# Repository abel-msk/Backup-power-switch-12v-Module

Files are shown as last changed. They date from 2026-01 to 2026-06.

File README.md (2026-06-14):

#Power backup board

Board for 12v power switch.  Plain power and battery backup.  Switchng provided by LM393 comparator. Both compared   line are adjustable by potentiometer.
Equipped with:
Battery 3S charger, 
Two INA219 i2c sensors
ESP32-C3 wifi board
Charge and done charger led signals passed to ESP
1x External connector for i2c line and charger status 
1x Connector with SPI for ext display
4x 12v power connector

First version
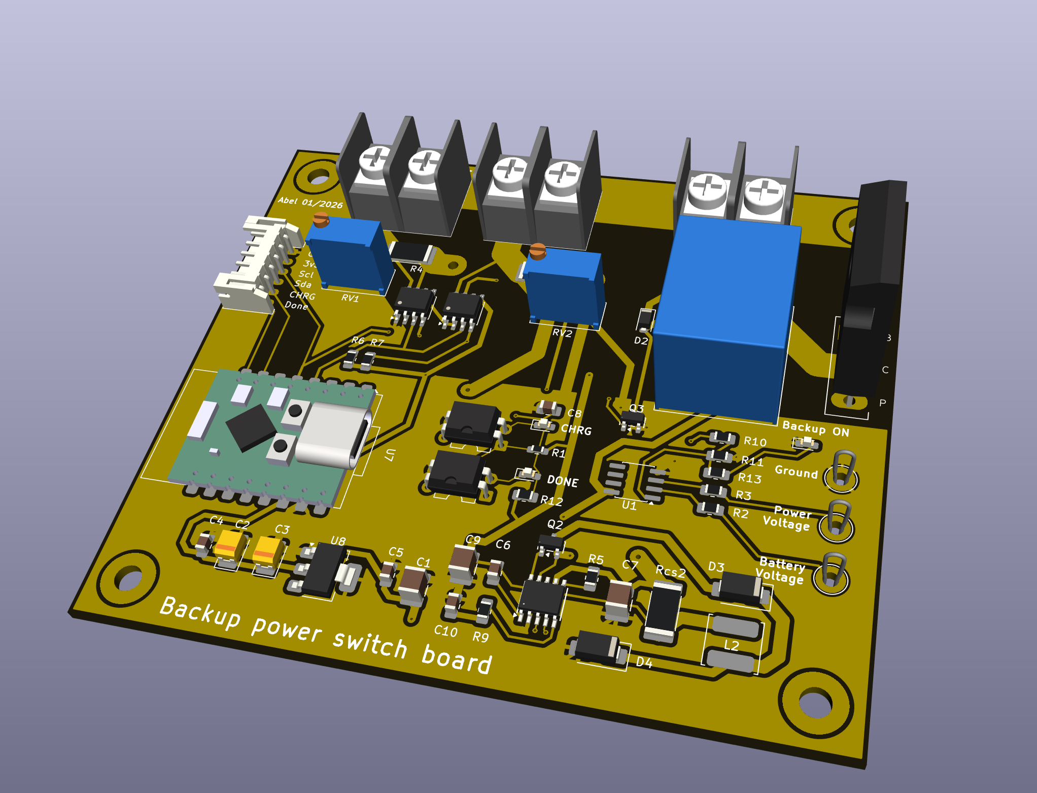
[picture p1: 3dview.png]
3D View


Current version v3.1
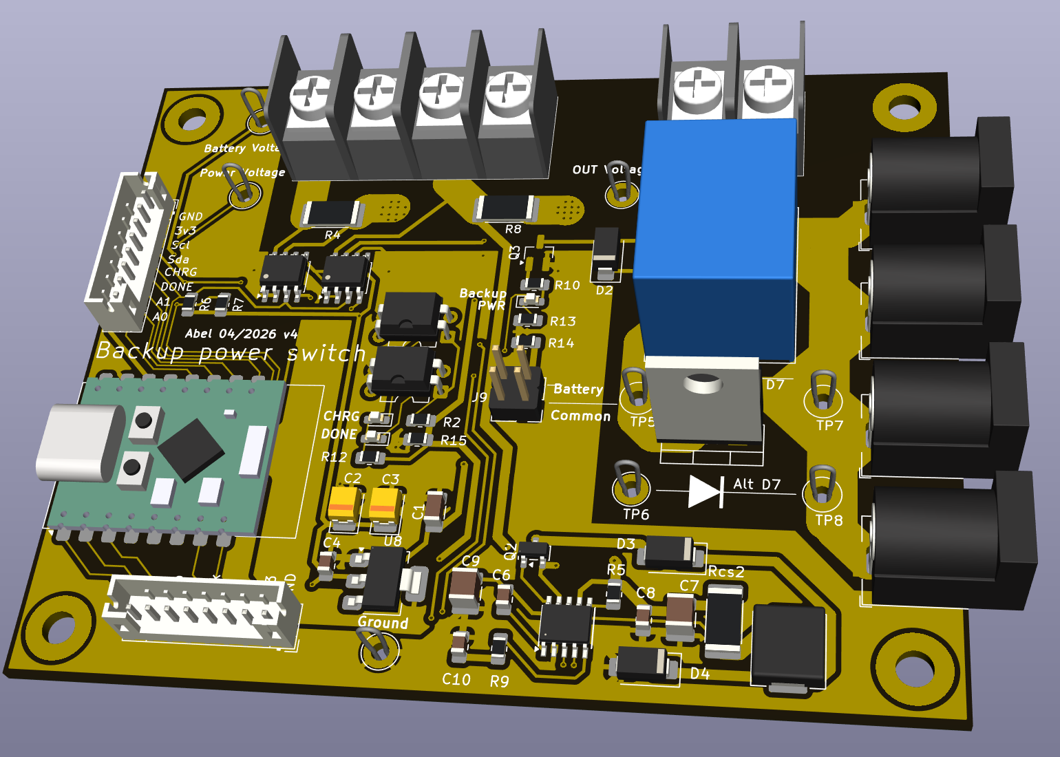
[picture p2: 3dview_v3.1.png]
3D View v3.1


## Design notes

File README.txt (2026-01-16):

# Power backup board

Board for 12v power switch.  Plain power and battery backup.  Switchng provided by LM393 comparator. Both compared   line are adjustable by potentiometer.
Equipped with:
Battery 3S charger, 
Two INA219 i2c sensors
ESP32-C3 wifi board
Charge and done charger passed to ESP
External connector for i2x line and charger status

3D View

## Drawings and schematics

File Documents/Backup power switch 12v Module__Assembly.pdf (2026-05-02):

AB

AB

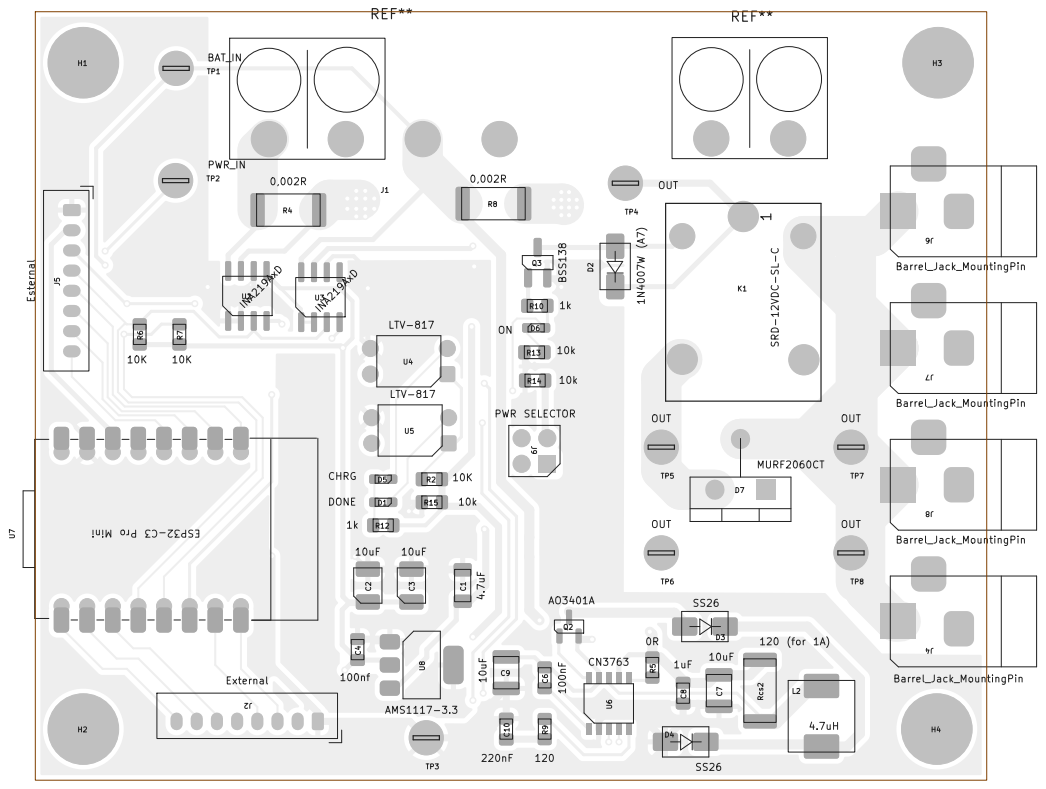
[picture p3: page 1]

Board2Pdf: Light Colors Placement TOP - Page 1/2

Sheet: Light Colors Placement TOP
File: Backup power switch 12v Module.kicad_pcb
Title:
KiCad E.D.A. 10.0.1

TP8 C8 C9 | D2 | Rcs2 U8 | U6 U7 | D7 U3 Antenna 1 | 2 | 3 | 4 | 5 | 6

AB

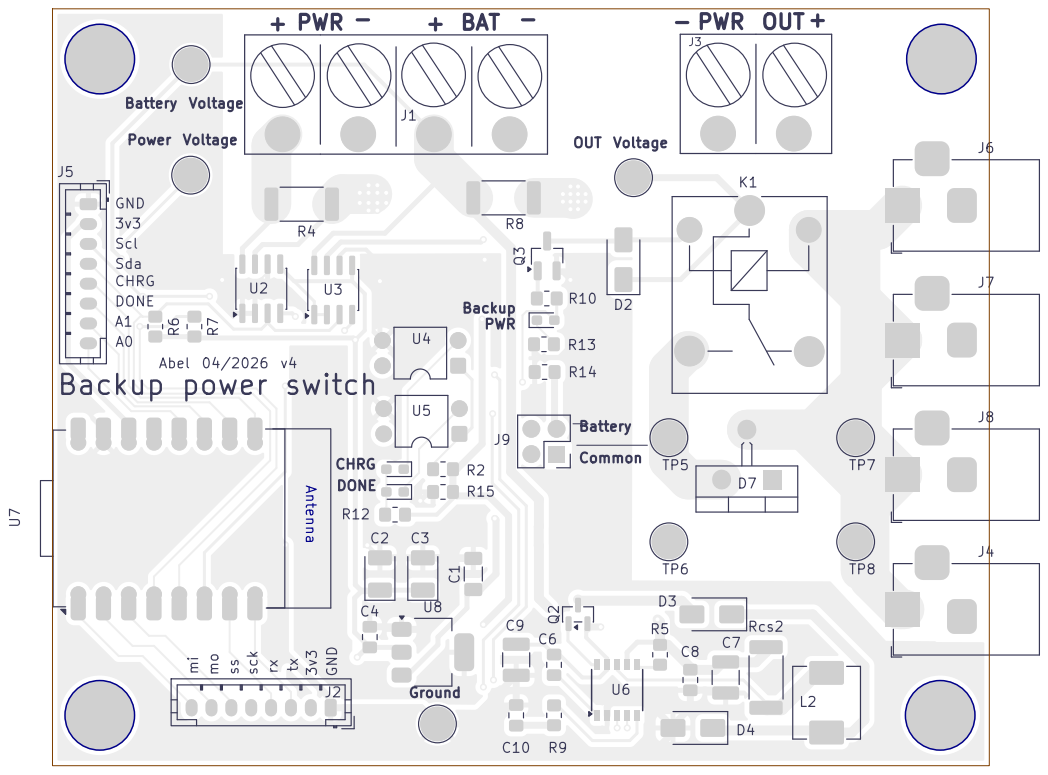
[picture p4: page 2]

Board2Pdf: Light Colors PCB Fabrication TOP - Page 2/2

Sheet: Light Colors PCB Fabrication TOP
File: Backup power switch 12v Module.kicad_pcb
Title:
KiCad E.D.A. 10.0.1

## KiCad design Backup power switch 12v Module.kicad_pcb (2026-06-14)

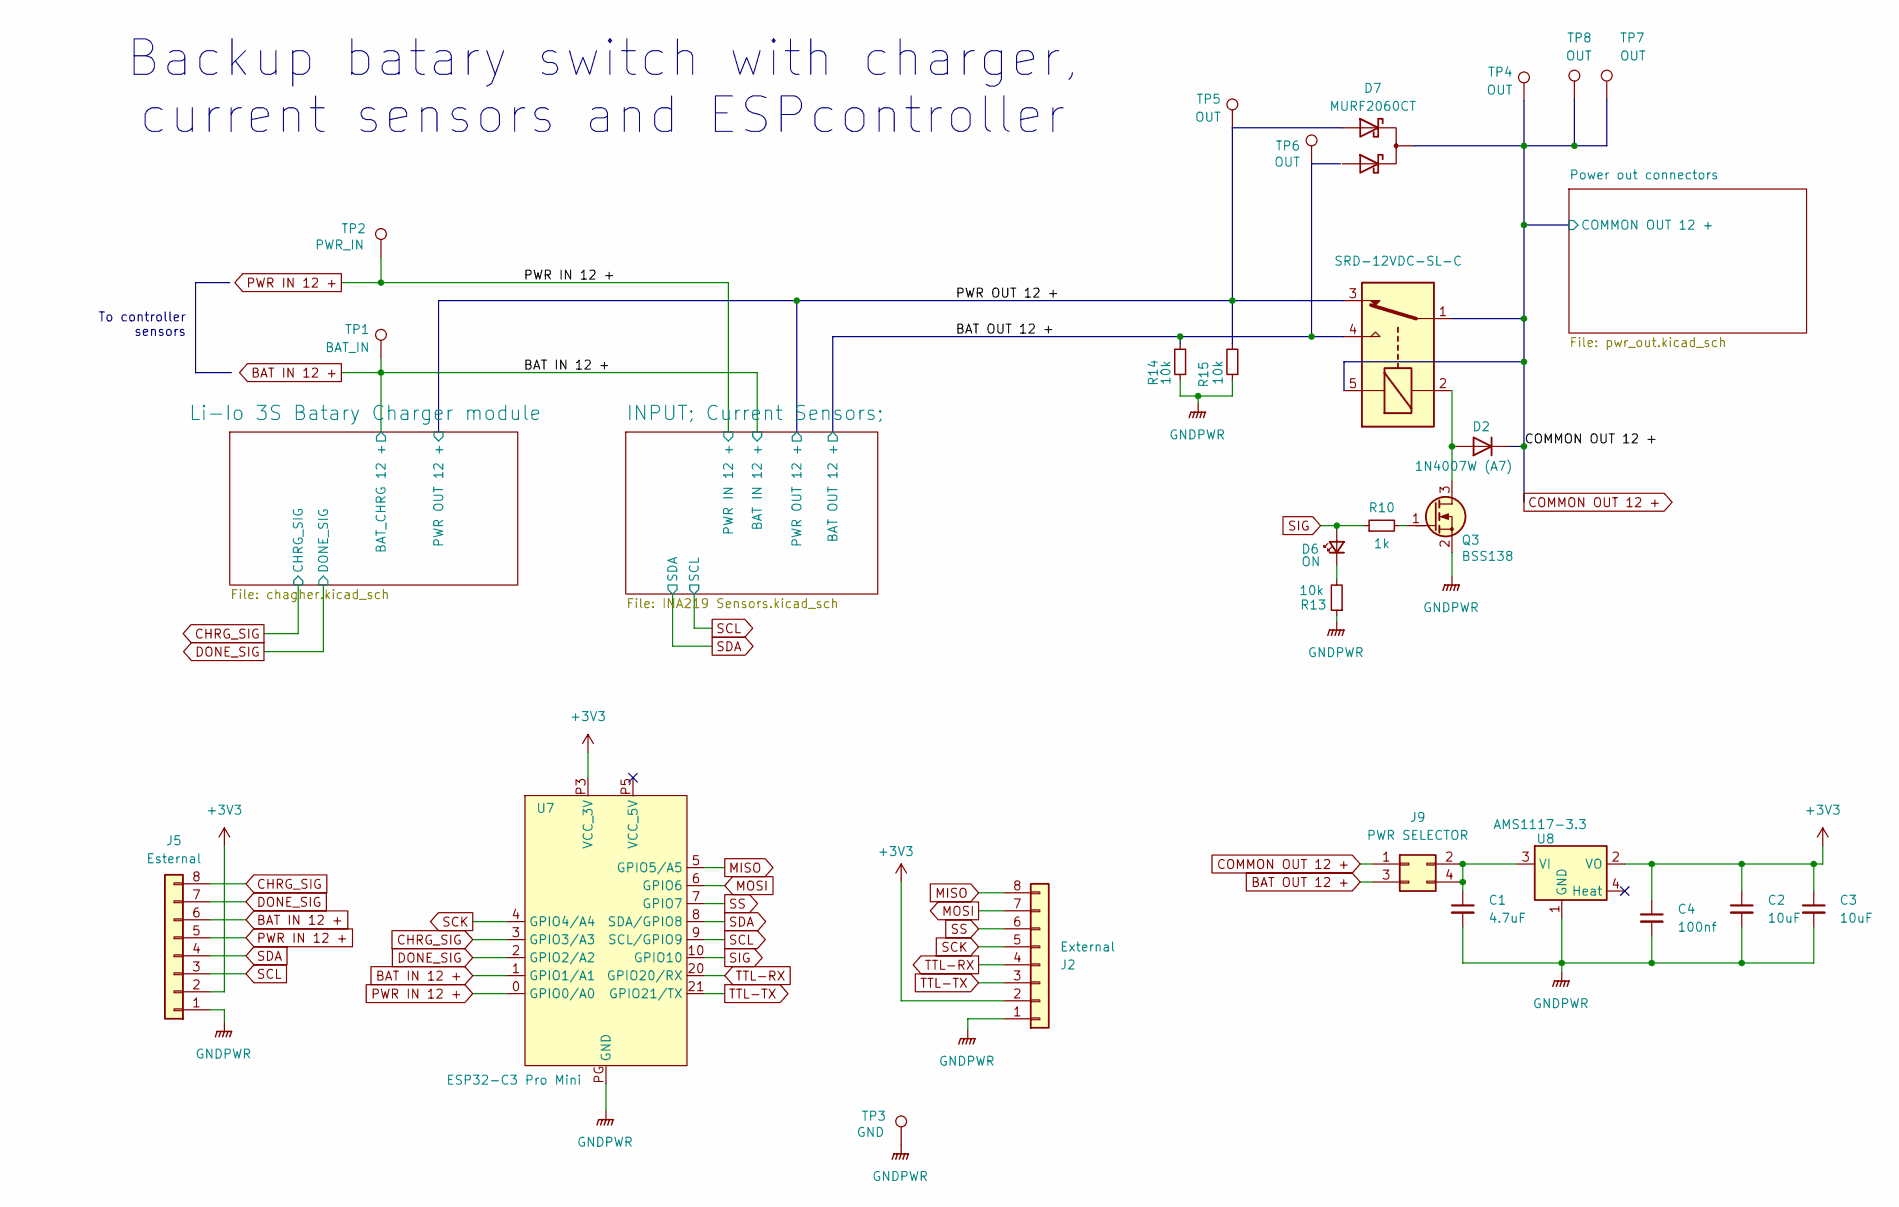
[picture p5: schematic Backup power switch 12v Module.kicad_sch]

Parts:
C1: 4.7uF; C_1206_3216Metric_Pad1.33x1.80mm_HandSolder
C2, C3: 10uF; CP_EIA-3528-21_Kemet-B_HandSolder
C4: 100nf; C_0805_2012Metric_Pad1.18x1.45mm_HandSolder
D2: 1N4007W (A7); D_SMA
D6: ON; LED_0603_1608Metric_Pad1.05x0.95mm_HandSolder
D7: MURF2060CT; TO-220-3_Staggered_Vertical
J2: External; JST_PH_B8B-PH-K_1x08_P2.00mm_Vertical
J5: Esternal; JST_PH_B8B-PH-K_1x08_P2.00mm_Vertical
J9: PWR SELECTOR; PinHeader_2x02_P2.54mm_Vertical
K1: SRD-12VDC-SL-C; Relay_SPDT_SANYOU_SRD_Series_Form_C
Q3: BSS138; SOT-23
R10: 1k; R_0805_2012Metric_Pad1.20x1.40mm_HandSolder
R13, R14, R15: 10k; R_0805_2012Metric_Pad1.20x1.40mm_HandSolder
TP1: BAT_IN; TestPoint_Loop_D2.50mm_Drill1.85mm
TP2: PWR_IN; TestPoint_Loop_D2.50mm_Drill1.85mm
TP3: GND; TestPoint_Loop_D2.50mm_Drill1.85mm
TP4, TP5, TP6, TP7, TP8: OUT; TestPoint_Loop_D2.50mm_Drill1.85mm
U7: ESP32-C3 Pro Mini; ESP32-C3_Pro_mini_pin
U8: AMS1117-3.3; SOT-223

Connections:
+3V3: C2.1, C3.1, C4.1, J2.2, J5.2, U7.P3 (VCC_3V), U8.2 (VO); also elsewhere on the board
/PWR OUT 12 +: D7.3 (A2), K1.3, R15.2, TP5.1 (1_1); also elsewhere on the board
BAT IN 12 +: J5.6, TP1.1 (1_1), U7.1 (GPIO1/A1); also elsewhere on the board
BAT OUT 12 +: J9.3, K1.4, R14.2, TP6.1 (1_1); also elsewhere on the board
CHRG_SIG: J5.8, U7.3 (GPIO3/A3); also elsewhere on the board
COMMON OUT 12 +: D2.1 (K), D7.2 (K), J9.1, K1.1, K1.5, TP4.1 (1_1), TP7.1 (1_1), TP8.1 (1_1); also elsewhere on the board
DONE_SIG: J5.7, U7.2 (GPIO2/A2); also elsewhere on the board
GNDPWR: C1.2, C2.2, C3.2, C4.2, J2.1, J5.1, Q3.2 (S), R13.1, R14.1, R15.1, TP3.1 (1_1), U7.PG (GND), U8.1 (GND); also elsewhere on the board
MISO: J2.8, U7.5 (GPIO5/A5)
MOSI: J2.7, U7.6 (GPIO6)
unnamed: D2.2 (A), K1.2, Q3.3 (D)
unnamed: D6.1 (K), R13.2
unnamed: C1.1, J9.2, J9.4, U8.3 (VI)
unnamed: Q3.1 (G), R10.2
PWR IN 12 +: J5.5, TP2.1 (1_1), U7.0 (GPIO0/A0); also elsewhere on the board
SCK: J2.5, U7.4 (GPIO4/A4)
SCL: J5.3, U7.9 (SCL/GPIO9); also elsewhere on the board
SDA: J5.4, U7.8 (SDA/GPIO8); also elsewhere on the board
SIG: D6.2 (A), R10.1, U7.10 (GPIO10)
SS: J2.6, U7.7 (GPIO7)
TTL-RX: J2.4, U7.20 (GPIO20/RX)
TTL-TX: J2.3, U7.21 (GPIO21/TX)

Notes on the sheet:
Backup batary switch with charger, current sensors and ESPcontroller
To controller sensors

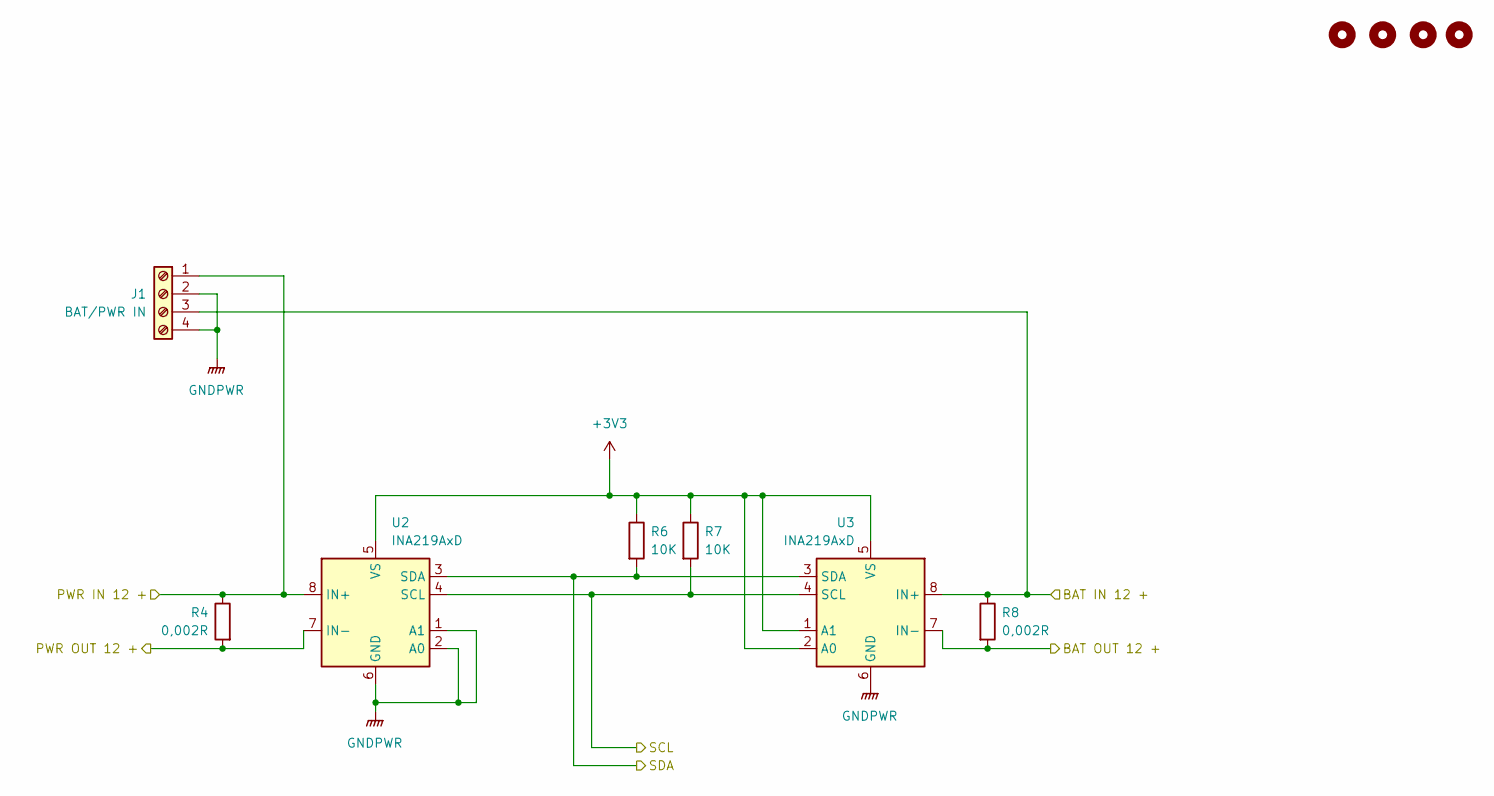
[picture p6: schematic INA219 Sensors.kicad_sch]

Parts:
H1, H2, H3, H4: MountingHole; MountingHole_3.5mm_Pad_TopBottom
J1: BAT/PWR IN; ScrewTerminal_KF7.62_4P
R4, R8: 0,002R; R_2512_6332Metric_Pad1.40x3.35mm_HandSolder
R6, R7: 10K; R_0805_2012Metric_Pad1.20x1.40mm_HandSolder
U2, U3: INA219AxD; SOIC-8_3.9x4.9mm_P1.27mm

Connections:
+3V3: R6.1, R7.1, U2.5 (VS), U3.1 (A1), U3.2 (A0), U3.5 (VS); also elsewhere on the board
/PWR OUT 12 +: R4.2, U2.7 (IN-); also elsewhere on the board
BAT IN 12 +: J1.3, R8.1, U3.8 (IN+); also elsewhere on the board
BAT OUT 12 +: R8.2, U3.7 (IN-); also elsewhere on the board
GNDPWR: J1.2, J1.4, U2.1 (A1), U2.2 (A0), U2.6 (GND), U3.6 (GND); also elsewhere on the board
PWR IN 12 +: J1.1, R4.1, U2.8 (IN+); also elsewhere on the board
SCL: R7.2, U2.4 (SCL), U3.4 (SCL); also elsewhere on the board
SDA: R6.2, U2.3 (SDA), U3.3 (SDA); also elsewhere on the board

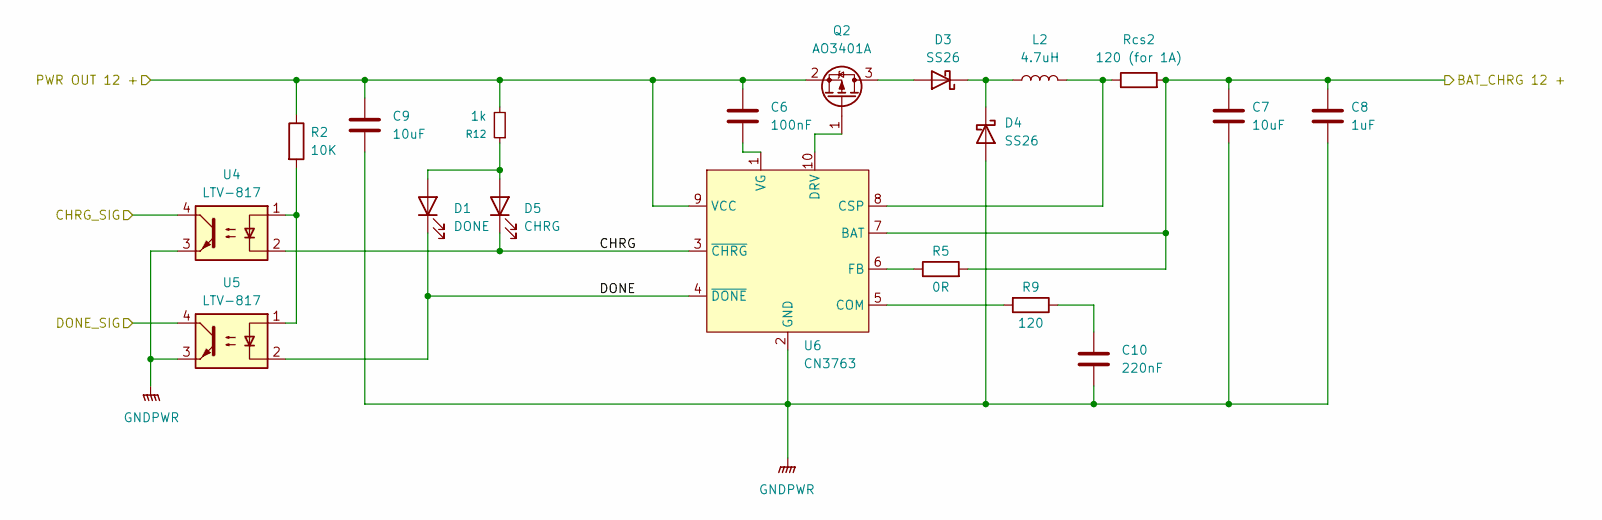
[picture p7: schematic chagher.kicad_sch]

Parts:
C6: 100nF; C_0805_2012Metric_Pad1.18x1.45mm_HandSolder
C7, C9: 10uF; C_1210_3225Metric_Pad1.33x2.70mm_HandSolder
C8: 1uF; C_0805_2012Metric_Pad1.18x1.45mm_HandSolder
C10: 220nF; C_0805_2012Metric_Pad1.18x1.45mm_HandSolder
D1: DONE; LED_0603_1608Metric_Pad1.05x0.95mm_HandSolder
D3, D4: SS26; D_SMA
D5: CHRG; LED_0603_1608Metric_Pad1.05x0.95mm_HandSolder
L2: 4.7uH; L_TechFuse_SL0624
Q2: AO3401A; SOT-23
R2: 10K; R_0805_2012Metric_Pad1.20x1.40mm_HandSolder
R5: 0R; R_0805_2012Metric_Pad1.20x1.40mm_HandSolder
R9: 120; R_0805_2012Metric_Pad1.20x1.40mm_HandSolder
R12: 1k; R_0805_2012Metric_Pad1.20x1.40mm_HandSolder
Rcs2: 120 (for 1A); R_2512_6332Metric_Pad1.40x3.35mm_HandSolder
U4, U5: LTV-817; DIP-4_W7.62mm
U6: CN3763; SSOP-10_3.9x4.9mm_P1.00mm

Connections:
/Li-Io 3S Batary Charger module/CHRG: D5.1 (K), U4.2, U6.3 (~CHRG)
/Li-Io 3S Batary Charger module/DONE: D1.1 (K), U5.2, U6.4 (~DONE)
/PWR OUT 12 +: C6.1, C9.1, Q2.2 (S), R2.1, R12.2, U6.9 (VCC); also elsewhere on the board
BAT IN 12 +: C7.1, C8.1, R5.2, Rcs2.2, U6.7 (BAT); also elsewhere on the board
CHRG_SIG: U4.4; also elsewhere on the board
DONE_SIG: U5.4; also elsewhere on the board
GNDPWR: C7.2, C8.2, C9.2, C10.2, D4.2 (A), U4.3, U5.3, U6.2 (GND); also elsewhere on the board
unnamed: C10.1, R9.1
unnamed: D1.2 (A), D5.2 (A), R12.1
unnamed: D3.2 (A), Q2.3 (D)
unnamed: D3.1 (K), D4.1 (K), L2.1
unnamed: Q2.1 (G), U6.10 (DRV)
unnamed: R2.2, U4.1, U5.1
unnamed: R9.2, U6.5 (COM)
unnamed: L2.2, Rcs2.1, U6.8 (CSP)
unnamed: R5.1, U6.6 (FB)
unnamed: C6.2, U6.1 (VG)

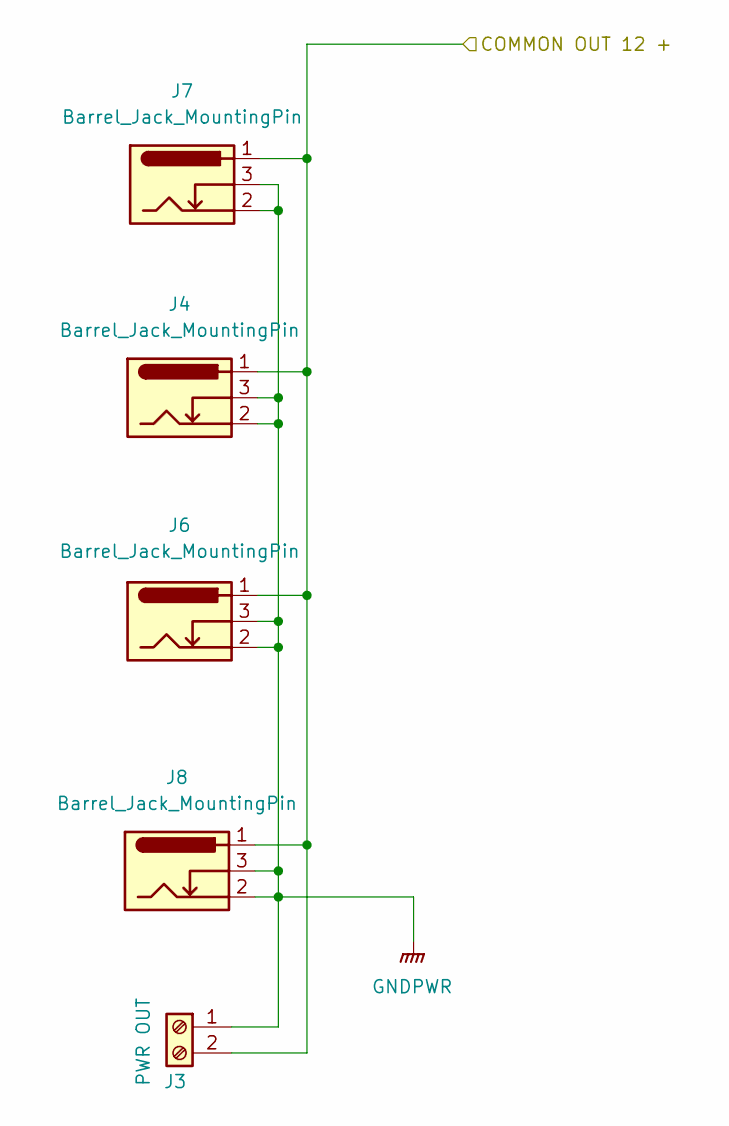
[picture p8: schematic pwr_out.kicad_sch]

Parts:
J3: PWR OUT; ScrewTerminal_KF7.62_2P
J4, J6, J7, J8: Barrel_Jack_MountingPin; BarrelJack_Horizontal

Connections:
COMMON OUT 12 +: J3.2, J4.1, J6.1, J7.1, J8.1; also elsewhere on the board
GNDPWR: J3.1, J4.2, J4.3, J6.2, J6.3, J7.2, J7.3, J8.2, J8.3; also elsewhere on the board

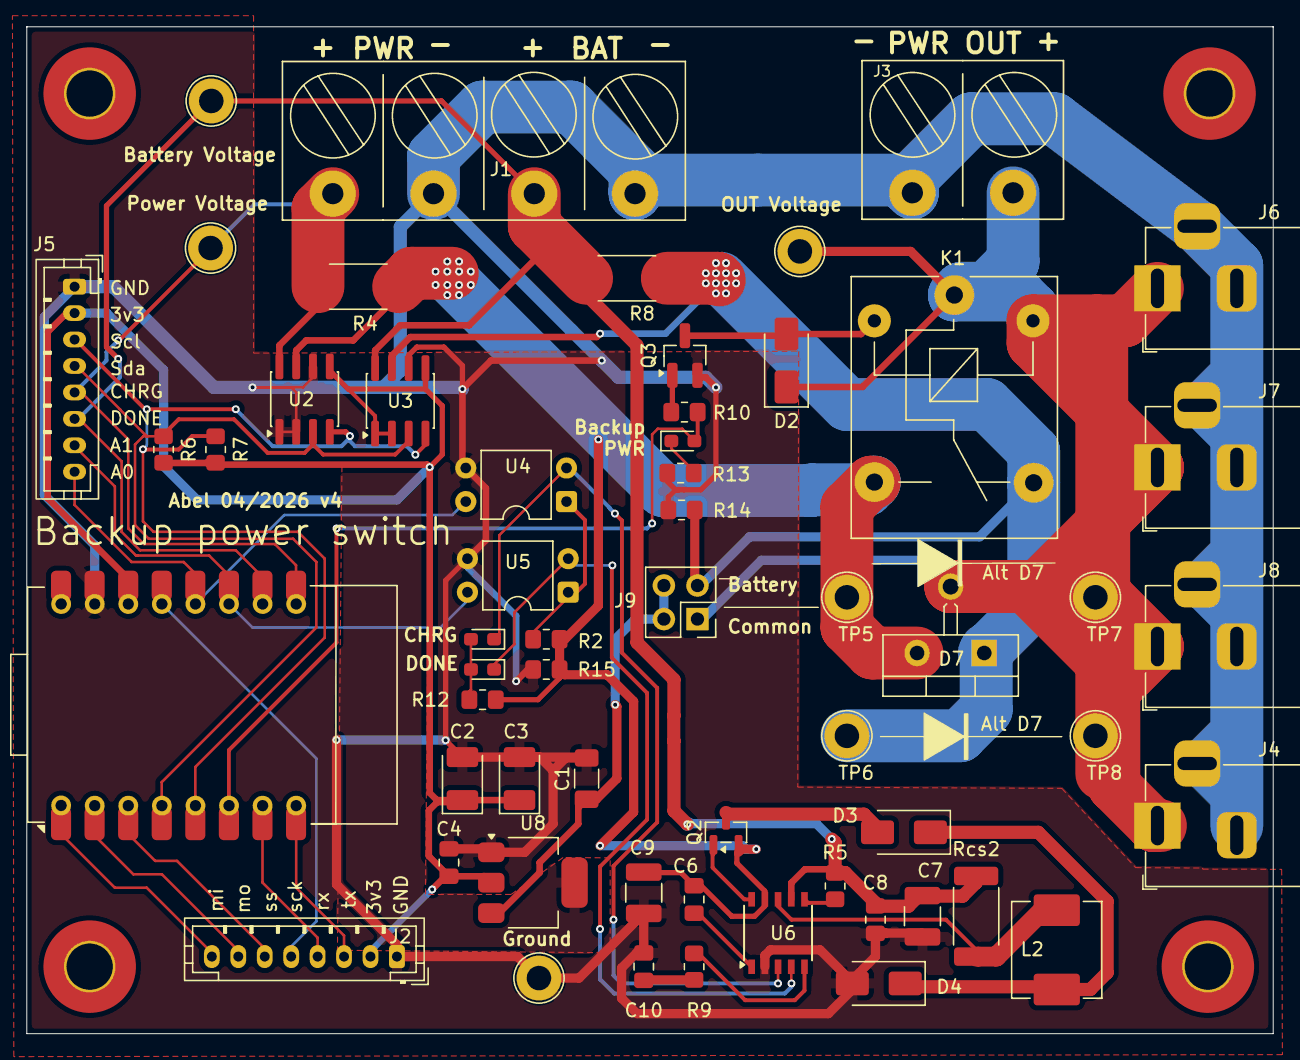
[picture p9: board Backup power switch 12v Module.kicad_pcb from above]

Board: 2 copper layers, 94.3 x 76.2 mm, 61 parts (0 on the bottom side), 34 nets.

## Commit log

2026-01-16 Fist release
    [Backup power switch 12v Module-B_Cu.gbr, Backup power switch 12v Module-B_Mask.gbr, Backup power switch 12v Module-B_Paste.gbr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]
2026-01-17 DRC check
    [Backup power switch 12v Module-B_Cu.gbr, Backup power switch 12v Module-B_Mask.gbr, Backup power switch 12v Module-B_Paste.gbr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]
2026-02-08 Add bat input stabilizer
    [Backup power switch 12v Module-B_Cu.gbr, Backup power switch 12v Module-B_Mask.gbr, Backup power switch 12v Module-B_Paste.gbr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]
2026-02-08 add stab scheme
    [StepDown Convertor.kicad_sch]
2026-02-08 Fix comparator out signal pullup
    [Backup power switch 12v Module-B_Cu.gbr, Backup power switch 12v Module-B_Mask.gbr, Backup power switch 12v Module-B_Paste.gbr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]
2026-02-12 Some sheme clarify
    [Backup power switch 12v Module.kicad_sch]
2026-02-14 Add power sockwr
    [Backup power switch 12v Module.kicad_pcb, Backup power switch 12v Module.kicad_sch, INA219 Sensors.kicad_sch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]
2026-02-28 Clean space for second relay
    [Backup power switch 12v Module.kicad_pcb, Backup power switch 12v Module.kicad_sch, INA219 Sensors.kicad_sch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]
2026-03-01 Fix charger in/out nammes
    [Backup power switch 12v Module.kicad_pcb, Backup power switch 12v Module.kicad_sch, chagher.kicad_sch]
2026-03-29 Some fixes
    [Backup power switch 12v Module.kicad_pcb]
2026-04-19 Move to kikad10
    [Backup power switch 12v Module.kicad_pcb, Backup power switch 12v Module.kicad_sch, INA219 Sensors.kicad_sch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]
2026-05-02 Add more space aroung relay
    [Backup power switch 12v Module.kicad_pcb, Backup power switch 12v Module.kicad_sch]
2026-05-02 Add holes for alt diodes. Prod. Docs
    [Backup power switch 12v Module-B_Cu.gbr, Backup power switch 12v Module-B_Mask.gbr, Backup power switch 12v Module-B_Paste.gbr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]
2026-06-14 add info
    [Backup power switch 12v Module.kicad_pcb]
2026-11-06 Adjusted the component values in the charging circuit and added a voltage divider for the A0 and A1 lines for ESP
2026-11-06 remove unused circuit
2026-11-06 Swap DONE_SIG and SS on ESP32: DONE_SIG to GPIO7, SS to GPIO2
    GPIO2 is an ESP32-C3 strapping pin; the optocoupler on DONE_SIG could
    pull it low at reset. SS (display CS) moved to GPIO2 with a new R20 10k
    pull-up to 3V3. Includes current PCB routing work.
2026-11-06 Revert schematic and PCB to v5.0
    Drop the DONE_SIG/SS swap (GPIO2<->GPIO7) and R20. PSU will be set to
    12.6 V instead of adding a boost for the charger; U5 will not be
    populated, so GPIO2 stays pulled high by R19.
2026-11-06 Mark U5/D1 DNP, fix R18/R19 orientation, update README
    - U5 (DONE optocoupler) and D1 (DONE LED) not populated: with a 12.6 V
    PSU the CN3763 never asserts DONE; GPIO2 stays pulled high by R19.
    - R18/R19 rotated 180 deg on the PCB so their pads match the routed
    tracks (v5.0 had 4 unconnected items there).
    - README: current circuit description, connector table, known issues
    and limitations, v5.0 3D render.
